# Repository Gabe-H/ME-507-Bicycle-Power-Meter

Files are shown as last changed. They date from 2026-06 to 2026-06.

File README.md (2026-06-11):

# ME-507 Bicycle Power Meter

A custom bicycle crank power meter built with **nRF Connect SDK** and **Zephyr RTOS**. The project measures crank bending strain and motion using custom hardware, estimates crank state with an extended Kalman filter, computes bicycle power, and broadcasts the result over Bluetooth Low Energy using a Cycling Power Service style interface.

This repository contains the firmware, custom Zephyr board/device-tree support, sensor and BLE libraries, and hardware design files for a custom PCB-based bicycle power meter.

## Project Overview

This project is intended to run on Nordic nRF52 hardware using the nRF Connect SDK. It combines:

- Strain/load measurement through an external ADC
- IMU-based crank motion sensing
- Sensor fusion and state estimation using an embedded Kalman filter
- Power calculation from measured torque and angular velocity
- BLE transmission to compatible cycling/fitness devices
- Custom PCB hardware files for the physical power meter electronics

The firmware is organized as a multi-threaded Zephyr application, with separate source files for IMU sampling, ADC sampling, filtering, battery monitoring, BLE communication, and power measurement.

## Repository Structure

```text
.
├── Hardware/                  # Mechanical/PCB-related design outputs
├── boards/                    # Zephyr board overlays for the target hardware
├── config/                    # Additional project configuration files
├── dts/bindings/sensor/       # Custom Zephyr device-tree bindings
├── lib/                       # Project libraries and drivers
├── src/                       # Main application source code
├── CMakeLists.txt             # Zephyr application build file
├── prj.conf                   # Main Zephyr project configuration
├── debug_nus.conf             # Optional BLE NUS debug configuration (WIP)
└── west.yml                   # West manifest, including external module references
```

## Firmware Architecture

The application is built around Zephyr RTOS threads and inter-thread communication. The main functional blocks are:

- `imu_thread`: samples the IMU and provides crank motion data
- `adc_thread`: samples the strain/load measurement front end
- `filter_thread`: runs sensor fusion and filtering logic
- `battery_thread`: monitors battery/fuel-gauge state
- `ble_thread`: advertises and sends measurements over BLE
- `power_meas`: computes torque, angular velocity, cadence, and power-related quantities
- `app_ipc`: shared application messaging and synchronization helpers

The firmware is configured for RTT logging and BLE peripheral operation. Floating-point support is enabled for the filtering and power calculation code.

## Libraries

Several project-specific libraries live in `/lib`.

### `lib/ble`

Bluetooth Low Energy support for the power meter. This project is intended to expose measured cycling power data through a custom implementation based on the BLE Cycling Power Service style of operation.

An optional Nordic UART Service configuration is also present for debug builds, allowing debug or telemetry output over BLE NUS when enabled.

### `lib/eekf`

Embedded Extended Kalman Filter support used for IMU/state estimation. The filter helps fuse noisy sensor measurements into a more useful estimate of crank state for downstream power calculations.

### `lib/icm40609`

Driver/support code for the ICM-40609-D IMU used for crank motion sensing. The IMU provides accelerometer and gyroscope data used by the filtering and power calculation pipeline.

### `lib/icm20948`

Legacy support for the ICM-20948 IMU, which was used in earlier hardware revisions.

### `lib/max17048`

Driver/support code for the MAX17048 battery fuel gauge.

### `lib/ads1220`

ADS1220 ADC support for high-resolution analog measurement. The ADS1220 support in this project is based on the work from [`badjeff/ads1220-zephyr-module`](https://github.com/badjeff/ads1220-zephyr-module), which is also referenced in the project `west.yml`.

## Hardware

The `Hardware/` directory contains custom hardware design files for the physical bicycle power meter. These files are intended to support a custom PCB and mechanical integration into a crank-arm-mounted power meter.

Current hardware-related files include:

- Gerber CAM/manufacturing outputs
- Fusion 360 export
- STEP model output

## Bluetooth Output

The project is designed to send calculated cycling power data over BLE so that standard cycling computers, fitness watches, or BLE-capable host devices can receive live power data.

The primary BLE path is based on a Cycling Power Service style interface. A debug configuration for Nordic UART Service is also included for development and telemetry use (WIP).

## Sensor Fusion and Power Calculation

The power meter estimates crank motion and loading from multiple sensors:

1. The ADC measures strain/load-related signals from the crank hardware.
2. The IMU measures acceleration and angular velocity.
3. The Kalman filter estimates useful crank state from noisy sensor inputs.
4. The application computes power from torque and angular velocity.
5. BLE packets transmit the calculated result.

The Kalman filter implementation is an important part of the project because it provides a structured way to combine IMU measurements with the mechanical model of the bicycle crank.

## Building

This is an **nRF Connect SDK / Zephyr RTOS** application.

Typical workflow:

```bash
west init -l .
west update
west build -b nrf52dk_nrf52832 .
west flash
```

Depending on the target hardware, board name, overlay files, and build configuration may need to be adjusted.

For nRF Connect for VS Code, open the repository as an existing nRF Connect application and create a build configuration for the desired board.

## Configuration Notes

The main firmware configuration is in:

```text
prj.conf
```

This enables core project features such as:

- GPIO
- I2C
- SPI
- ADC
- Zephyr input subsystem support
- RTT logging
- floating-point printf support
- FPU support
- BLE peripheral mode
- custom BLE device name

The optional NUS debug configuration is in:

```text
debug_nus.conf
```

## Development Status

This project is under active development as a college course bicycle power meter. Some modules are experimental, some are hardware-specific, and some library code may represent earlier hardware revisions or alternate sensor options.

## Credits

- ADS1220 Zephyr support is based on [`badjeff/ads1220-zephyr-module`](https://github.com/badjeff/ads1220-zephyr-module).
- Built with Nordic nRF Connect SDK and Zephyr RTOS.
- Developed as part of the Cal Poly ME-507 bicycle power meter project.

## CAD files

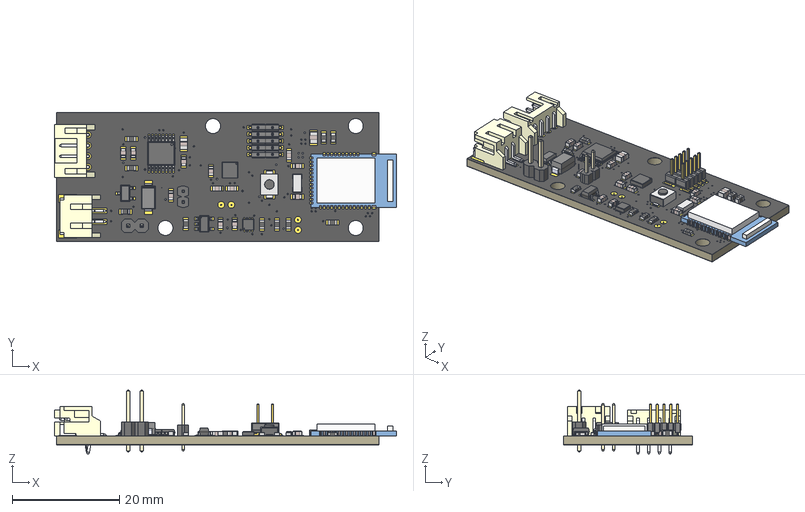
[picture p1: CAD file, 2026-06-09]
Hardware/Power Meter v3.step
63.9 x 24.1 x 11.9 mm

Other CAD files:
Hardware/Power Meter v3.f3z

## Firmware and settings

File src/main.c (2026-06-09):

/**
 * @file main.c
 * @author Gabe Haarberg
 * @brief Bicycle Power Meter project for ME-507 Spring 2026 at Cal Poly SLO.
 * @version 0.1
 * @date 2026-05-20
 *
 * @copyright Copyright (c) 2026
 *
 *
 * Written to be run on custom nRF52832-based PCB. Individual thread functions can be found in their src/ *_thread.c files
 */

/** BEGIN INCLUDES **/
// System
#include <stdio.h>
#include <zephyr/kernel.h>
#include <zephyr/logging/log.h>

#include "app_ipc.h"

/** END INCLUDES **/

/** Logger configuration **/
// LOG_MODULE_REGISTER(app, LOG_LEVEL_INF);
LOG_MODULE_REGISTER(app, LOG_LEVEL_DBG);

/**
 * @brief Zephyr thread for sending messages to RTT terminal
 *
 * Messages are sent as a char array pointer to the FIFO buffer
 */
void rtt_thread(void)
{
    // Post READY bit to sync event share
    k_event_post(&thread_sync_event, RTT_THREAD_READY);

    // Continue to main loop after START bit received
    k_event_wait(&thread_sync_event, START_BIT, false, K_FOREVER);

    return;
    // while (1)
    // {
    //     char *rx_data = k_fifo_get(&printk_fifo, K_FOREVER);

    //     puts(rx_data);
    //     k_free(rx_data);
    // }
}

/**
 * @brief Main thread. Coordinates all thread setup before allowing them to enter their loops
 *
 * See coordination configuration in app_ipc.h
 *
 */
int main(void)
{
    // Wait for all READY bit flags to be set
    // k_event_wait_all(&thread_sync_event, ALL_READY, false, K_FOREVER);
    LOG_INF("Waiting for threads to be ready");

    uint32_t events = 0;
    for (int i = 0; i < 10; i++)
    {
        events = k_event_test(&thread_sync_event, ALL_READY);

        LOG_DBG("Events: 0x%x", events);

        if ((events & ALL_READY) != ALL_READY)
            k_sleep(K_SECONDS(1));
        else
            break;
    }

    LOG_DBG("Checking events");
    events = k_event_wait_all(
        &thread_sync_event,
        ALL_READY,
        false,
        K_NO_WAIT);

    // Log error if not all threads started in time
    if ((events & ALL_READY) != ALL_READY)
    {
        LOG_ERR("Not all threads became ready. Got 0x%08X", events);
    }

    // Notify tasks to continue by setting START bit
    k_event_post(&thread_sync_event, START_BIT);

    LOG_DBG("Start bit sent to all threads");

    return 0; // Main thread no longer needed
}

K_THREAD_DEFINE(rtt_thread_id, STACKSIZE, rtt_thread, NULL, NULL, NULL, 7, 0, 0);

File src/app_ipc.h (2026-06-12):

#ifndef APP_IPC_H
#define APP_IPC_H

#include <zephyr/kernel.h>

/** Threading configuration**/
#define STACKSIZE 1024             // Stack area used by each thread
#define IMU_DATA_SLAB_NUM_BLOCKS 5 // Number of blocks to allocate for IMU memory slab
#define IMU_DATA_SLAB_ALIGNMENT 8  // Need 8 because data is dealing with int64_t
#define AXIS_DATA_SLAB_NUM_BLOCKS 5
#define AXIS_DATA_SLAB_ALIGNMENT 8
#define BLE_DATA_SLAB_NUM_BLOCKS 5
#define BLE_DATA_SLAB_ALIGNMENT 8

/** Thread coordination */
#define ADC_THREAD_READY BIT(0)
#define BATTERY_THREAD_READY BIT(1)
#define BLE_THREAD_READY BIT(2)
#define FILTER_THREAD_READY BIT(3)
#define IMU_THREAD_READY BIT(4)
#define RTT_THREAD_READY BIT(5)
#define PWR_THREAD_READY BIT(6)

#define ALL_READY (/* ADC_THREAD_READY | */                 \
                   BATTERY_THREAD_READY |                   \
                   BLE_THREAD_READY | FILTER_THREAD_READY | \
                   IMU_THREAD_READY | RTT_THREAD_READY |    \
                   PWR_THREAD_READY)

#define START_BIT BIT(7) // START BIT is 1 higher than highest thread bit

/** IMU Timing */
#define IMU_PERIOD 50 // IMU data update period in milliseconds

#define FORWARD_DIR // Gyro in right-hand-rule
// #define REVERSE_DIR // Gyro in left-hand-rule

/**
 * @brief Struct containing relevant info from IMU
 *
 * @param accel_x Acceleration in X-dir [ g ]
 * @param accel_y Acceleration in Y-dir [ g ]
 * @param accel_z Acceleration in Z-dir [ g ]
 * @param gyro_x  Gyro angular vel in X-dir [ dps ]
 * @param gyro_y  Gyro angular vel in Y-dir [ dps ]
 * @param gyro_z  Gyro angular vel in Z-dir [ dps ]
 * @param ts Timestamp. Millis since boot [ ms ]
 */
struct imu_data_t
{
    float accel_x; // Acceleration in X-dir [ g ]
    float accel_y; // Acceleration in Y-dir [ g ]
    float accel_z; // Acceleration in Z-dir [ g ]
    float gyro_x;  // Gyro angular vel in X-dir [ dps ]
    float gyro_y;  // Gyro angular vel in Y-dir [ dps ]
    float gyro_z;  // Gyro angular vel in Z-dir [ dps ]
    int64_t ts;    // Timestamp. Millis since boot [ ms ]
};

/**
 * @brief Struct containing data to be sent via BLE
 *
 * @param power Estimated power output at cranks [W]
 */
struct ble_data_t
{
    uint16_t initialized; // Honestly just a place holder to make this struct of size 8U for slab alignment
    uint16_t power;       // Estimated power output [W]
    uint16_t crank_index;
    uint16_t crank_event_time;
};

/**
 * @brief Struct containing outputs from Kalman filter
 *
 */
struct filter_data_t
{
    float theta;               // Estimated angle [rad]
    float omega;               // Estimated omega [rad/s]
    uint16_t crank_index;      // Rotation index (used for CPS)
    uint16_t crank_event_time; // Rotation time (used for CPS)
    int64_t ts;                // Uptime timestamps [ms]
};

/**
 * @brief Event with mask to sync thread startup process
 *
 */
extern struct k_event thread_sync_event;

/**
 * @brief FIFO buffer of pointers to `imu_data_t` data packets
 * stored on `imu_data_slab`
 *
 */
extern struct k_fifo imu_fifo;

/**
 * @brief Zephyr-based memory management for IMU data
 *
 */
extern struct k_mem_slab imu_data_slab;

/**
 * @brief FIFO buffer of pointers to `ble_data_t` data packets
 * stored on `ble_data_slab`
 *
 */
extern struct k_fifo ble_fifo;

/**
 * @brief Zephyr-based memory management for cycling data to be sent over BLE
 *
 */
extern struct k_mem_slab ble_data_slab;

/**
 * @brief FIFO buffer of pointers to `filter_data_t` data packets
 * stored on `filter_data_slab`
 *
 */
extern struct k_fifo filter_fifo;

/**
 * @brief Zephyr-based memory management for IMU data
 *
 */
extern struct k_mem_slab filter_data_slab;

/**
 * @brief Mutex for axis (Strain gauge ADC) value sharing
 * so that no task is reading the value while another is
 * writing to it
 *
 */
extern struct k_mutex axis_latest_lock;

/**
 * @brief Shared strain gauge ADC value. Take `axis_latest_lock` mutex
 * before accessing.
 *
 */
extern int32_t axis_latest_value;

#endif /* APP_IPC_H */

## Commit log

2026-05-14 Initial commit for Power_Meter_Breadboard
2026-05-14 Update spi pins
2026-05-23 Add battery monitor. Use Segger RTT. Expand ICM-40609 library to enable gyro readings
2026-05-23 Add accelerometer data. TODO: Investigate why 1g is not shown in a direction (Z)
2026-05-25 Convert to threaded system. Begin ADS1220 support.
2026-05-25 IMU comments
2026-05-29 ADS1220 ADC working with strain gauges
2026-05-31 Add battery voltage read function
2026-05-31 Move ADC task to own file
2026-05-31 Move filter task (previously angle_task) to its own file
2026-06-01 Use slab for ADC (instead of FIFO)
2026-06-01 Move battery monitor task to its own file
2026-06-01 Fix battery logging. Remove old includes
    [main.c]
2026-06-01 Rename "task" -> "thread"
2026-06-01 Add thread synchronization
2026-06-04 Add torque measurement
2026-06-05 Apply averaging filter in power_meas. Send power data over BLE
2026-06-05 Add debugging logs for thread event coordination
2026-06-09 Add Hardware files
    [Power Meter v3.f3z, Power Meter v3.step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]
2026-06-11 Update thread task sizes (entered manually for now). Use events for ble host connected - other threads can run now while ble is disconnected!
2026-06-11 Remove stale ADC thread
2026-06-11 Update thread priorities
2026-06-12 Fix up alternate physical configuration settings
    [app_ipc.h]
